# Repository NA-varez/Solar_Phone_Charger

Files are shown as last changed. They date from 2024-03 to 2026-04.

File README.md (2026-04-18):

# Solar_Phone_Charger

<!-- PROJECT LOGO -->
<br />
<div align="center">
  <a href="https://github.com/NA-varez/Solar_Phone_Charger">
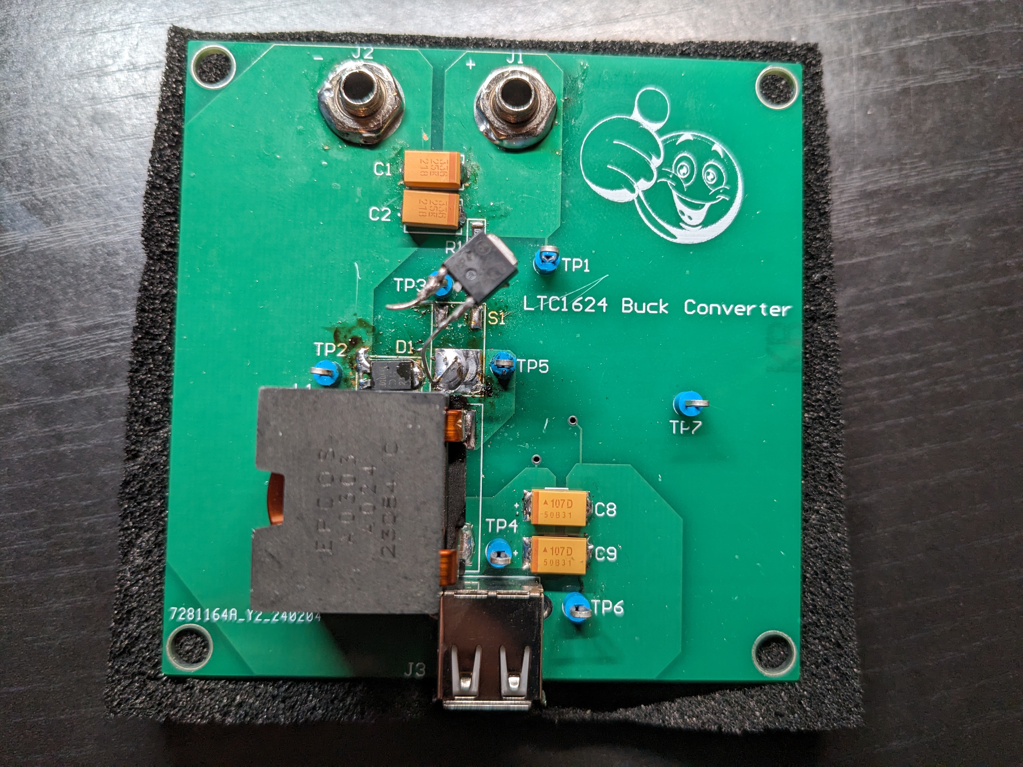
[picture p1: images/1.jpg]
    
  </a>

  <p align="center">
    DC-DC Buck Converter with input from solar panel to a USB-A output
    <br />
  </p>
</div>

<!-- USAGE EXAMPLES -->
## How it Works
1. The DC-DC Buck Converter uses an LTC1624 200kHz fixed-frequency switching controller. 
2. Input is taken from a provided small solar panel and connected via banana plugs. 
3. Filtered with input capacitors, power flows through an RSENSE resistor that sets the max output current and then to the Drain of a MOSFET. 
4. Power flows through the switch and Schottky Diode through the inductor and output to a USB-A connection after some filtering capacitors.

<!-- ABOUT THE PROJECT -->
## Project Pictures!

<div align="center">
  <a href="https://github.com/NA-varez/Solar_Phone_Charger">
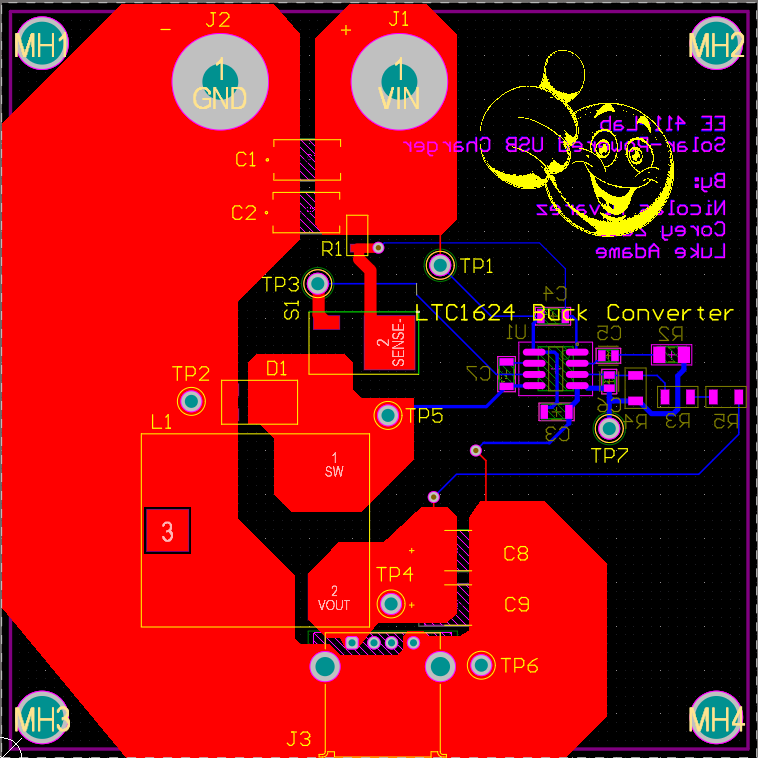
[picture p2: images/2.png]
    
  </a>
</div>

<div align="center">
  <a href="https://github.com/NA-varez/Solar_Phone_Charger">
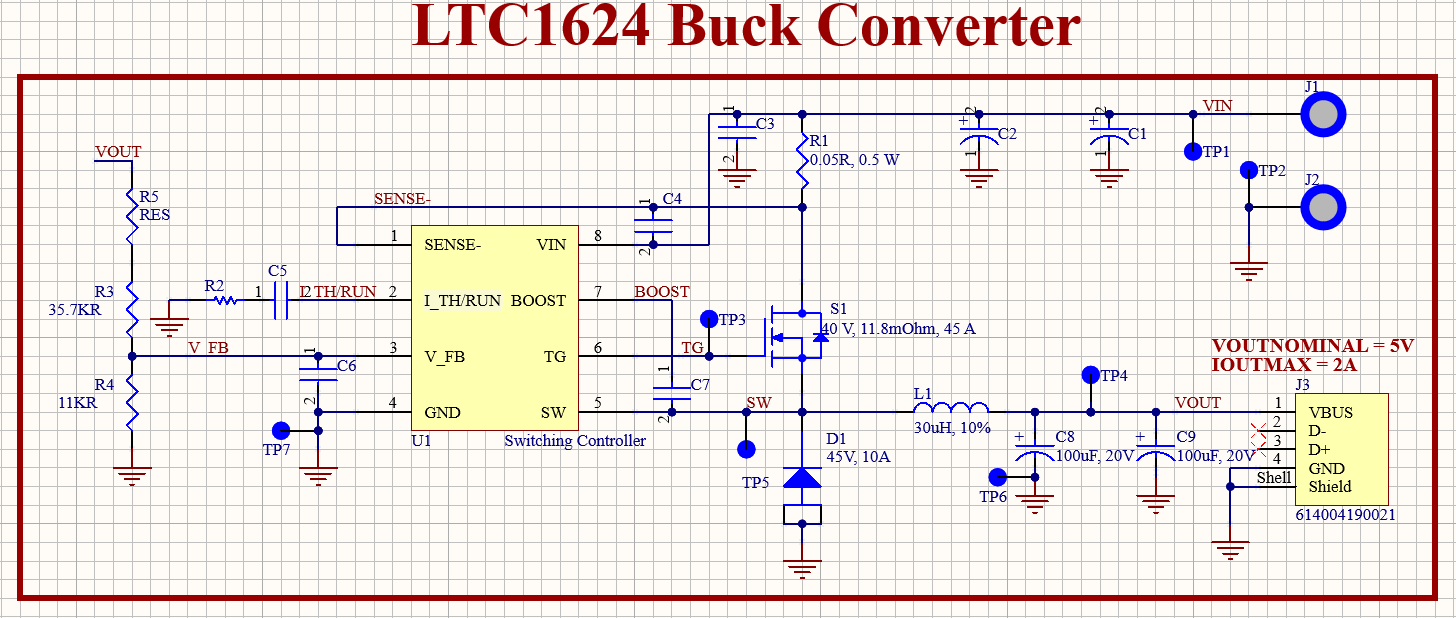
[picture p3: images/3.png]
    
  </a>
</div>

### Software Used

* Altium 
* Gerber Viewer 7.0 
* LTspice for simulation

## Debugging Steps

1. Observe any damages to components or extreme heat emanating from the board
2. Check that your input supply is turned ON. Start with NO-LOAD at the output.
3. Check Input and Output connections. Make sure they are electrically sound
4. Perform point-point continuity testing with a multimeter using probes
5. Probe GND and move through every connection making sure there are no unwanted shorts to GND
6. Check the footprints. It's possible the pins assigned to the footprints do not correctly reflect the pins of the device (In our case the MOSFET's pin connections were mismatched on the footprint
7. Verify that the simulation where you derived the component values from is reflected in your design
8. Verify any significant nodes (Such as the switching node) look as expected

## Roadmap

- [X] Choose a switching controller
- [x] Follow a LTC1624 Design guide to bias for 5V output and 2A max current
- [X] Simulate controller in LTspice to find minimum component values for desired Line and Load Regulation specs
- [X] Design review with professor -> Make necessary/suggested changes to design
- [X] Order board (Used JLC PCB)
- [X] Assemble and test board
- [X] Make changes to ECAD files after any errors are found
- [X] Get oscilloscope captures
- [X] Add documentation of equations used Add BOM

## Contributors

* Nicolas Alvarez - nalvar95@outlook.com - www.linkedin.com/in/nicolas-alvarez-69061b1b6
* Luke Adame - lukeadame@yahoo.com
* Corey Zaas - coreyzaas@gmail.com

## Acknowledgments

* [Footprint Reference Guide](https://www.slideshare.net/abishus/smt-notes)
* Professor Taufik - Cal Poly

:smile:

<p align="right">(<a href="#readme-top">back to top</a>)</p>

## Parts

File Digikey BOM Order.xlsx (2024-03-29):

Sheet: Sheet1
# | QUANTITY | PART NUMBER | MANUFACTURER PART NUMBER | DESCRIPTION | CUSTOMER REFERENCE | UNIT PRICE | EXTENDED PRICE
1 | 10 | 399-C1206C104J5RAC7800CT-ND | C1206C104J5RAC7800 | CAP CER 0.1UF 50V X7R 1206 | OTHER DECOUPLING CAPS | 0.166 | 1.66
2 | 10 | 399-C0805C471J5GAC7210CT-ND | C0805C471J5GAC7210 | CAP CER 470PF 50V C0G/NP0 0805 | COMPENSATION CAP | 0.076 | 0.76
3 | 10 | 399-C0805C101K5GAC7210CT-ND | C0805C101K5GAC7210 | CAP CER 100PF 50V C0G/NP0 0805 | IC DECOUPLING | 0.059 | 0.59
4 | 3 | 31-SDT10A45P5-13DCT-ND | SDT10A45P5-13D | DIODE SCHOTTKY 45V 10A POWERDI5 | Schottky | 0.51 | 1.53
5 | 3 | 495-B82559A0303A024CT-ND | B82559A0303A024 | FIXED IND 30UH 22.9A 3.6MOHM SMD | Inductor | 8.34 | 25.02
6 | 4 | 273-KDV12DR050ETCT-ND | KDV12DR050ET | RES 0.05 OHM 0.5% 1/2W 1206 | RSENSE | 0.46 | 1.84
7 | 3 | P18836CT-ND | ERA-8ARW3572V | RES SMD 35.7KOHM 0.05% 1/4W 1206 | FEEDBACK | 1.53 | 4.59
8 | 4 | NVD5C478NLT4GOSCT-ND | NVD5C478NLT4G | MOSFET N-CH 40V 14A/45A DPAK | SWITCH | 1.65 | 6.60
9 | 22 | 36-5287-ND | 5287 | TEST POINT (BLUE) - MULTIPURPOSE | TP | 0.281 | 6.18
10 | 10 | 399-8384-1-ND | T491D336M025AT | CAP TANT 33UF 20% 25V 2917 | INPUT CAPS | 0.983 | 9.83
11 | 10 | 399-17909-1-ND | C1206C102K1GECAUTO | CAP CER 1206 1NF 100V C0G 10% | IC CAPS | 0.165 | 1.65
12 | 10 | 478-1724-1-ND | TAJD107K020RNJ | CAP TANT 100UF 10% 20V 2917 | OUTPUT CAPS | 0.844 | 8.44
13 | 10 | P11.0KFCT-ND | ERJ-8ENF1102V | RES SMD 11K OHM 1% 1/4W 1206 | FEEDBACK | 0.091 | 0.91
14 | 3 | P6.8KBCCT-ND | ERA-8AEB682V | RES SMD 6.8K OHM 0.1% 1/4W 1206 | RCOMPENSATION | 0.37 | 1.11

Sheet: Sheet2
Total Cost | Part # | Description | Quantity | Cost Per Unit | Link
$46.82 | LTC1624IS8#TRPBF | THE CONTROLLER | 1 | $11.26 | https://www.digikey.com/en/products/detail/analog-devices-inc/LTC1624IS8-TRPBF/959496
 | NVD5C478NLT4G | THE SWITCH | 1 | $1.65 | https://www.digikey.com/en/products/detail/onsemi/NVD5C478NLT4G/8636558?gad_source=1
 | SDT10A45P5-13D | Schottky diode | 1 | $0.51 | https://www.digikey.com/en/products/detail/diodes-incorporated/SDT10A45P5-13D/9769518
 | B82559A0303A024 | OUTPUT INDUCTOR 30 uH | 1 | $8.34 | https://www.digikey.com/en/products/detail/epcos-tdk-electronics/B82559A0303A024/13165572
 | ERA-8ARW113V | 11k Feedback resistor (R4) | 1 | $1.53 | https://www.digikey.com/en/products/detail/panasonic-electronic-components/ERA-8ARW113V/5141136 | 1206
 | ERA-8ARW3572V | 35.7k Feedback resistor (R3) | 1 | $1.53 | https://www.digikey.com/en/products/detail/panasonic-electronic-components/ERA-8ARW3572V/5163062 | 1206
 | KDV12DR050ET | RSENSE (R1) | 1 | $0.46 | https://www.digikey.com/en/products/detail/ohmite/KDV12DR050ET/10476615 | 1206
 | ERA-8AEB682V | 6.8k Compensation Resistor (R2) | 1 | $0.37 | https://www.digikey.com/en/products/detail/panasonic-electronic-components/ERA-8AEB682V/3071143 | 1206
 | C1206C102F1GAC7800 | 1000pF (C4) | 1 | $0.98 | https://www.digikey.com/en/products/detail/kemet/C1206C102F1GAC7800/2214981 | 1206
 | C1206C104J5RACTU | 0.1uF (C7) | 2 | $0.25 | https://www.digikey.com/en/products/detail/kemet/C1206C104J5RAC7800/411249 | 1206
 | C0805C101K5GAC7210 | 100pF (C6) | 1 | $0.10 | https://www.digikey.com/en/products/detail/kemet/C0805C101K5GAC7210/12700401 | 0805 (2012)
 | C0805C471J5GAC7210 | 470pF Compensation Capacitor (C5) | 1 | $0.11 | https://www.digikey.com/en/products/detail/kemet/C0805C471J5GAC7210/12701387 | 805
 | T510X107M020ATE040 | Output capacitor 100uH (C8/9) | 2 | $7.00 | https://www.digikey.com/en/products/detail/kemet/T510X107M020ATE040/992042 | 2917 (7343)
 | T495X336M035ATE100 | 33uF (C1/2) | 2 | $2.74 | https://www.digikey.com/en/products/detail/kemet/T495X336M035ATE100/8763808 | 2917

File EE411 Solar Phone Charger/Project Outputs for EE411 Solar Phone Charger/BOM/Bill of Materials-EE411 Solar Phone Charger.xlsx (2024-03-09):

Comment | Description | Designator | Footprint | LibRef | Quantity
Switching Controller | Switching Controller, Current-mode, 2A, 225kHz Switching Freq-Max, CMOS, PDSO8 | U1 | LTC1624 | LTC1624IS8#TRPBF | 1
5287 | Blue Test Point | TP1, TP2, TP3, TP4, TP5, TP6, TP7 | KEYSTONE_5287 | 5287 | 7
40 V, 11.8mOhm, 45 A | Single N-Channel Power MOSFET, 40V, 45A, 7.7mΩ DPAK 2500 tape and reel | S1 | DPAKSWITCH | NVD5C478NLT4G | 1
RES | Generic 1206 Resistor | R5 | R1206 | RES | 1
11KR | Fixed Resistor, Thin Film, 0.25W, 11000ohm, 150V, 0.05% +/-Tol, 10ppm/Cel, Surface Mount, 1206 | R4 | R1206 | ERA-8ARW113V | 1
35.7KR | 1206 Thin Film Chip Resistor / 1206 SMD Resistor 0.05% 10PPM 35.7 Kohm | R3 | R1206 | ERA-8ARW3572V | 1
ERA8AEB682V |  | R2 | RESC3216X70X50NL20T25 | CMP-2003-04491-1 | 1
0.05R, 0.5 W | Fixed Resistor, Metal Film, 0.5W, 0.05ohm, 0.5% +/-Tol, 100ppm/Cel, Surface Mount, 1206 | R1 | R1206 | KDV12DR050ET | 1
30uH, 10% | General Purpose Inductor, 30uH, 10%, 1 Element, Ferrite-Core, SMD, 9790 | L1 | ERU24 | B82559A0303A024 | 1
614004190021 |  | J3 | 614004190021 | CMP-1502-03228-2 | 1
4MM Banana Female Socket |  | J1, J2 | 4MM Banana Female Socket | 4MM Banana Female Socket | 2
45V, 10A | Diode Schottky 45V 10A 5-Pin PowerDI T/R | D1 | PowerDI5 | SDT10A45P5-13D | 1
100uF, 20V | TR3D107K020C0080 Surface Mount Tantalum Capacitor, 100 uF, 20 V, ± 10%, -55 °C, 125 °C, 2917 [7343-31 Metric] | C8, C9 | FP-TR3D-MFG | CMP-00030-44433242-1 | 2
C0805C101K5GAC7210 | C0805 100 pF C0G 30ppm/°C 10.00% 50 V | C6 | FP-C0805C-DN-MFG | CMP-03020-002806-2 | 1
C0805C471J5GAC7210 | C0805 470 pF C0G 30ppm/°C 5.00% 50 V | C5 | FP-C0805C-DN-MFG | CMP-03020-030339-1 | 1
C1206C102F1GACTU | CAP CER 1000PF 100V 1% NP0 1206 | C4 | FP-C1206C-EB-MFG | CMP-03020-013132-1 | 1
C1206C104J5RACTU | Multilayer Ceramic Capacitor, C Series, 0.1 - F, - 5%, X7r, 50 V, 1206 [3216 Metric] Rohs Compliant: Yes | C3, C7 | FP-C1206C-EB-MFG | CMP-03020-003996-1 | 2
T495X336M035ATE100 | CAP TANT 33UF 20% 35V 2917 | C1, C2 | FP-T495X336M035ATE100-MFG | CMP-03017-000065-1 | 2

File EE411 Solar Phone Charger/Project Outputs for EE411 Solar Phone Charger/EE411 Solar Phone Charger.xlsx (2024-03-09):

Comment | Description | Designator | Manufacturer Part Number | Tolerance | Voltage Rating | Pricing 1 | Pricing | Quantity
T495X336M035ATE100 | CAP TANT 33UF 20% 35V 2917 | C1, C2 |  | 20% | 35V |  |  | 2
C1206C104J5RACTU | Multilayer Ceramic Capacitor, C Series, 0.1 - F, - 5%, X7r, 50 V, 1206 [3216 Metric] Rohs Compliant: Yes | C3, C7 | C1206C104J5RACTU | 0.05 | 50 V |  |  | 2
C1206C102F1GACTU | CAP CER 1000PF 100V 1% NP0 1206 | C4 | C1206C102F1GACTU | 0.01 | 100 V |  |  | 1
C0805C471J5GAC7210 | C0805 470 pF C0G 30ppm/°C 5.00% 50 V | C5 | C0805C471J5GAC7210 | 0.05 | 50 V |  |  | 1
C0805C101K5GAC7210 | C0805 100 pF C0G 30ppm/°C 10.00% 50 V | C6 | C0805C101K5GAC7210 | 0.1 | 50 V |  |  | 1
100uF, 20V | TR3D107K020C0080 Surface Mount Tantalum Capacitor, 100 uF, 20 V, ± 10%, -55 °C, 125 °C, 2917 [7343-31 Metric] | C8, C9 |  | 10% | 20V |  |  | 2
45V, 10A | Diode Schottky 45V 10A 5-Pin PowerDI T/R | D1 | SDT10A45P5-13D |  |  |  | 1=0.51, 10=0.394, 100=0.2362, 500=0.21866, 1000=0.14869, 2000=0.13689 (USD) | 1
4MM Banana Female Socket |  | J1, J2 |  |  |  |  |  | 2
614004190021 |  | J3 |  |  |  |  |  | 1
30uH, 10% | General Purpose Inductor, 30uH, 10%, 1 Element, Ferrite-Core, SMD, 9790 | L1 | B82559A0303A024 |  |  | 1=8.34, 10=7.194, 25=6.6724 (USD) |  | 1
0.05R, 0.5 W | Fixed Resistor, Metal Film, 0.5W, 0.05ohm, 0.5% +/-Tol, 100ppm/Cel, Surface Mount, 1206 | R1 | KDV12DR050ET |  |  |  | 1=0.46, 10=0.312, 25=0.2428, 50=0.179, 100=0.1245, 250=0.10856, 500=0.0895, 1000=0.06475 (USD) | 1
ERA8AEB682V |  | R2 |  |  |  |  |  | 1
35.7KR | 1206 Thin Film Chip Resistor / 1206 SMD Resistor 0.05% 10PPM 35.7 Kohm | R3 | ERA-8ARW3572V |  |  |  | 1=1.53, 10=1.056, 50=0.7948, 100=0.6991, 500=0.54712 (USD) | 1
11KR | Fixed Resistor, Thin Film, 0.25W, 11000ohm, 150V, 0.05% +/-Tol, 10ppm/Cel, Surface Mount, 1206 | R4 | ERA-8ARW113V | 0.05% |  |  | 1=1.53, 10=1.056, 50=0.7948, 100=0.6991, 500=0.54712 (USD) | 1
RES | Generic 1206 Resistor | R5 | ERA-8ARW3572V |  |  |  | 1=1.53, 10=1.056, 50=0.7948, 100=0.6991, 500=0.54712 (USD) | 1
40 V, 11.8mOhm, 45 A | Single N-Channel Power MOSFET, 40V, 45A, 7.7mΩ DPAK 2500 tape and reel | S1 | NVD5C478NLT4G |  |  | 1=1.65, 10=1.368, 100=1.0891, 500=0.92158, 1000=0.78194 (USD) |  | 1
5287 | Blue Test Point | TP1, TP2, TP3, TP4, TP5, TP6, TP7 |  |  |  |  |  | 7
Switching Controller | Switching Controller, Current-mode, 2A, 225kHz Switching Freq-Max, CMOS, PDSO8 | U1 | LTC1624IS8#TRPBF |  |  | 1=11.26, 10=10.351, 25=9.9216, 100=8.7419, 250=8.3128, 500=7.7765, 1000=7.13292 (USD) |  | 1

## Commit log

2024-03-09 recorded on github
    [Bill of Materials-EE411 Solar Phone Charger.xlsx, EE411 Solar Phone Charger.PrjPcb, EE411 Solar Phone Charger.xlsx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]
2024-03-29 Added BOM
    [Digikey BOM Order.xlsx]
